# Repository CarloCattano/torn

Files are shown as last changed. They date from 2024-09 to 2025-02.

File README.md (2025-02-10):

This is the 42 Berlin fork of the original torn v3 project. We would like to make this project available to anyone in the school who has interest, but first we want to reliably be able to build the project and document any extra steps here.

# First Build Troubleshooting Issues

- The OLED display still has glitching issues in a part of the display. We have resoldered it but the glitching persists. So it could be this is another electrical/software issue. This may only be resolved/diagnosed when we've built another one

# Documenting the 2nd Build

During the 2nd build we will try to document the trickier parts to pay attention and/or create new sections documentation that diverges from the original. So far we have identified the following issues:

1. Choice of Case

It helps to consider which case you might build even from the get-go, as it can affect which buttons you choose (see below) and for some cases the switches/keycaps need to be of a certain type.

What we tried to far:
- PCB Case: We noted that there are no .svg files provided for laser cutting the parts, we must create our own from the Kicad projects (base and plate). This requires a few design decisions (indent around USB connector etc)
- HiPro Case: Be aware that there are two variations here for MX or Choc switches

2. USB Connector

- These should be soldered and tested with someone with plenty of experience and getting it wrong can ruin the whole rest of the build.
- Right now we are hand soldering with the finest tip we have, and it's still tricky.
- As the pins do not stick out fully, an alternative approach could be to use solder paste, a heat gun and flux.
- We should consider redesigning this for a more hand-soldering friendly connector (if such a thing exists) 
- Without a solution here, it prevents the build from being achievable by all

3. Buttons

The choice of height of the two reset/boot buttons is important. For the first build we used very flat buttons, only later to discover that they are inaccessible when adding the transparent acrylic layer on top. The solution to this would be to use taller buttons (we have them in different sizes in a kit) and to cut holes in the acrylic layer to allow the buttons to poke through.

4. Flashing the Bootloader

We have an Arduino set aside in a box to help with flashing the bootloader
The original guide has the right instructions in terms of pinouts, but it's easy to the wiring up, so for 2nd build we should to document better how to wire the pins to the 6-pin header on the keyboard (photo)

5. Flashing the Firmware

There were two issues here that diverged from the build guide. We installed all the necessary dependencies and tools in the LabAdmin account on the computer on the left next to the window.

- QMKVia which torn v3 uses is no longer supported. We don't have a solution for this, as the support for it its dropped and requires manual intervention and investigation as mentioned in the author isse https://github.com/rtitmuss/torn/issues/29

- The make command to be run from the qmk_firmware folder is ```make torn:default:flash``` as opposed to the guide. Keyboard must be set to flashing mode.

6. Configuration

- A C file is used to configure the keyboard [keymap file](https://github.com/qmk/qmk_firmware/blob/master/keyboards/torn/keymaps/default/keymap.c). This could be improved by adding a wrapper. Any alterations require compiling and flashing to the chip, which could complicate things though

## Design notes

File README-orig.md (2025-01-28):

Torn
===============

The split keyboard kit made with through hole components. The design has been inspired by the [Corne](https://github.com/foostan/crkbd), [Plaid](https://github.com/hsgw/plaid) and [Discipline](https://github.com/coseyfannitutti/discipline) keyboards.

torn

Torn uses an Atmega328P cpu, running QMK with VUSB:
- [QMK firmware](https://github.com/qmk/qmk_firmware/blob/master/keyboards/torn/readme.md).
- [Bootloader](https://github.com/rtitmuss/USBaspLoader).
- Compatible with [VIA](https://caniusevia.com/)

## Building your own Torn keyboard

Later this year you will be able to buy a Torn keyboard kit from [splitkb.com](https://blog.splitkb.com/blog/january-2021).
Alternatively you can also buy [all the parts](./doc/bom.md) needed youself.

Instructions are in the [Build guide](./doc/build.md) and [Troubleshooting guide](./doc/troubleshoot.md).
You can ask questions and get help on the [Torn Discord channel](https://discord.gg/mamAqNccju).

There is also a detailed [build log](https://github.com/rafaeldelboni/buildlogs/blob/main/torn-v3.md)
and [video](https://www.youtube.com/watch?v=7WUTQ30Datw). Thanks [rafaeldelboni](https://github.com/rafaeldelboni)! 

## Thanks

It would not have been possible for me to design Torn without the information and designs published by the mechanical keyboard community. So thanks go to ...

### Guides

* [Corne Keyboard build log](https://thomasbaart.nl/2018/11/26/corne-keyboard-helidox-build-log/) was my first step into this rabbit hole ...
* [Keyboard PCB Guide](https://github.com/ruiqimao/keyboard-pcb-guide) a beginners guide to designing a keyboard PCB in KiCad
* [Guide: Keyboard Construction Explained](https://brianlee.blog/2018/11/23/guide-keyboard-construction-explained/)
* [Cheat sheet: Custom keyboard mounting styles](https://thomasbaart.nl/2019/04/07/cheat-sheet-custom-keyboard-mounting-styles/)

### PCB Design

* [KiCad](https://kicad.org/) for PCB design
* [Split keyboard comparison site](https://jhelvy.shinyapps.io/splitkbcompare/) to iterate on key layout
* [Keyboard layout editor](http://www.keyboard-layout-editor.com/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,%3B&@_y:-0.875&x:2%3B&=X&_x:1%3B&=V&_x:5%3B&=M&_x:1%3B&=.%3B&@_y:-0.875&x:5%3B&=B&_x:3%3B&=N%3B&@_y:-0.875&a:7%3B&=&_a:4%3B&=Z&_x:11&a:7%3B&=&=%3B&@_y:-0.2749999999999999&x:3%3B&=&_x:7%3B&=%3B&@_r:13&rx:3.5&ry:8.5&y:-5.4&x:-0.5%3B&=%3B&@_r:26&y:-1&x:-0.5%3B&=%3B&@_r:39&y:-1&x:-0.5%3B&=%3B&@_r:-39&rx:11.5&y:-5.4&x:-0.5%3B&=%3B&@_r:-26&y:-1&x:-0.5%3B&=%3B&@_r:-13&y:-1&x:-0.5%3B&=) for your layout
* [Plate & Case Builder](http://builder.swillkb.com/) Generate CAD files from KLE files
* [keyswitches.pretty](https://github.com/daprice/keyswitches.pretty) KiCad library of mechanical keyboard switch footprints 

### QMK Firmware

* [QMK](https://docs.qmk.fm/#/) Quantum Mechanical Keyboard firmware
* [REMAP](https://remap-keys.app/) to easily configure your keyboard online
* [VIA](https://caniusevia.com/) to configure your keyboard

### 3d Design

The following are great resources to get started with keyboard case design:

* [Fusion 360](https://www.autodesk.com/products/fusion-360/personal)
* [65% Keyboard Case Design](https://youtu.be/4P0zfLLblOw)
* [Hinged Box for 3D Printing](https://youtu.be/iSBsBTMsGTk)
* [Snap Fit Cases](https://www.youtube.com/watch?v=E0NVC8xhf3I)
* [Knurling for 3D Printing](https://www.youtube.com/watch?v=jKPbye0XtMk)

### Other Keyboards

I took inspiration from other keyboards I'd used or liked:

* [Kinesis Advantage](https://kinesis-ergo.com/shop/advantage2/) my daily driver and endgame for almost 20 years! Opps! 
* [Corne](https://github.com/foostan/crkbd)
* [Discipline](https://github.com/coseyfannitutti/discipline) (used with permission from [coseyfannitutti](https://github.com/coseyfannitutti/))
* [Plaid](https://github.com/hsgw/plaid)
* [Lily](https://docs-gitbook.keeb.io/docs/iris-rev3-build-guide)
* [Dactyl](https://raw.githubusercontent.com/adereth/dactyl-keyboard/master/guide/circuit-diagram.png)

## License



The Torn Keyboard is licensed under [Creative Commons Attribution-NonCommercial 4.0 International License](https://creativecommons.org/licenses/by-nc/4.0).

This PCB design may be freely reproduced, modified, and manufactured for personal use only. If you would like to use this design commercially please contact me at richard.titmuss@gmail.com to request permission.
 
## Gallery

Build Photo

Torn Keyboard

Wedge Case

Choc Switches

HiPro Case

3d Case

Torn Keyboard

Torn Keyboard

Torn Keyboard

Torn Keyboard

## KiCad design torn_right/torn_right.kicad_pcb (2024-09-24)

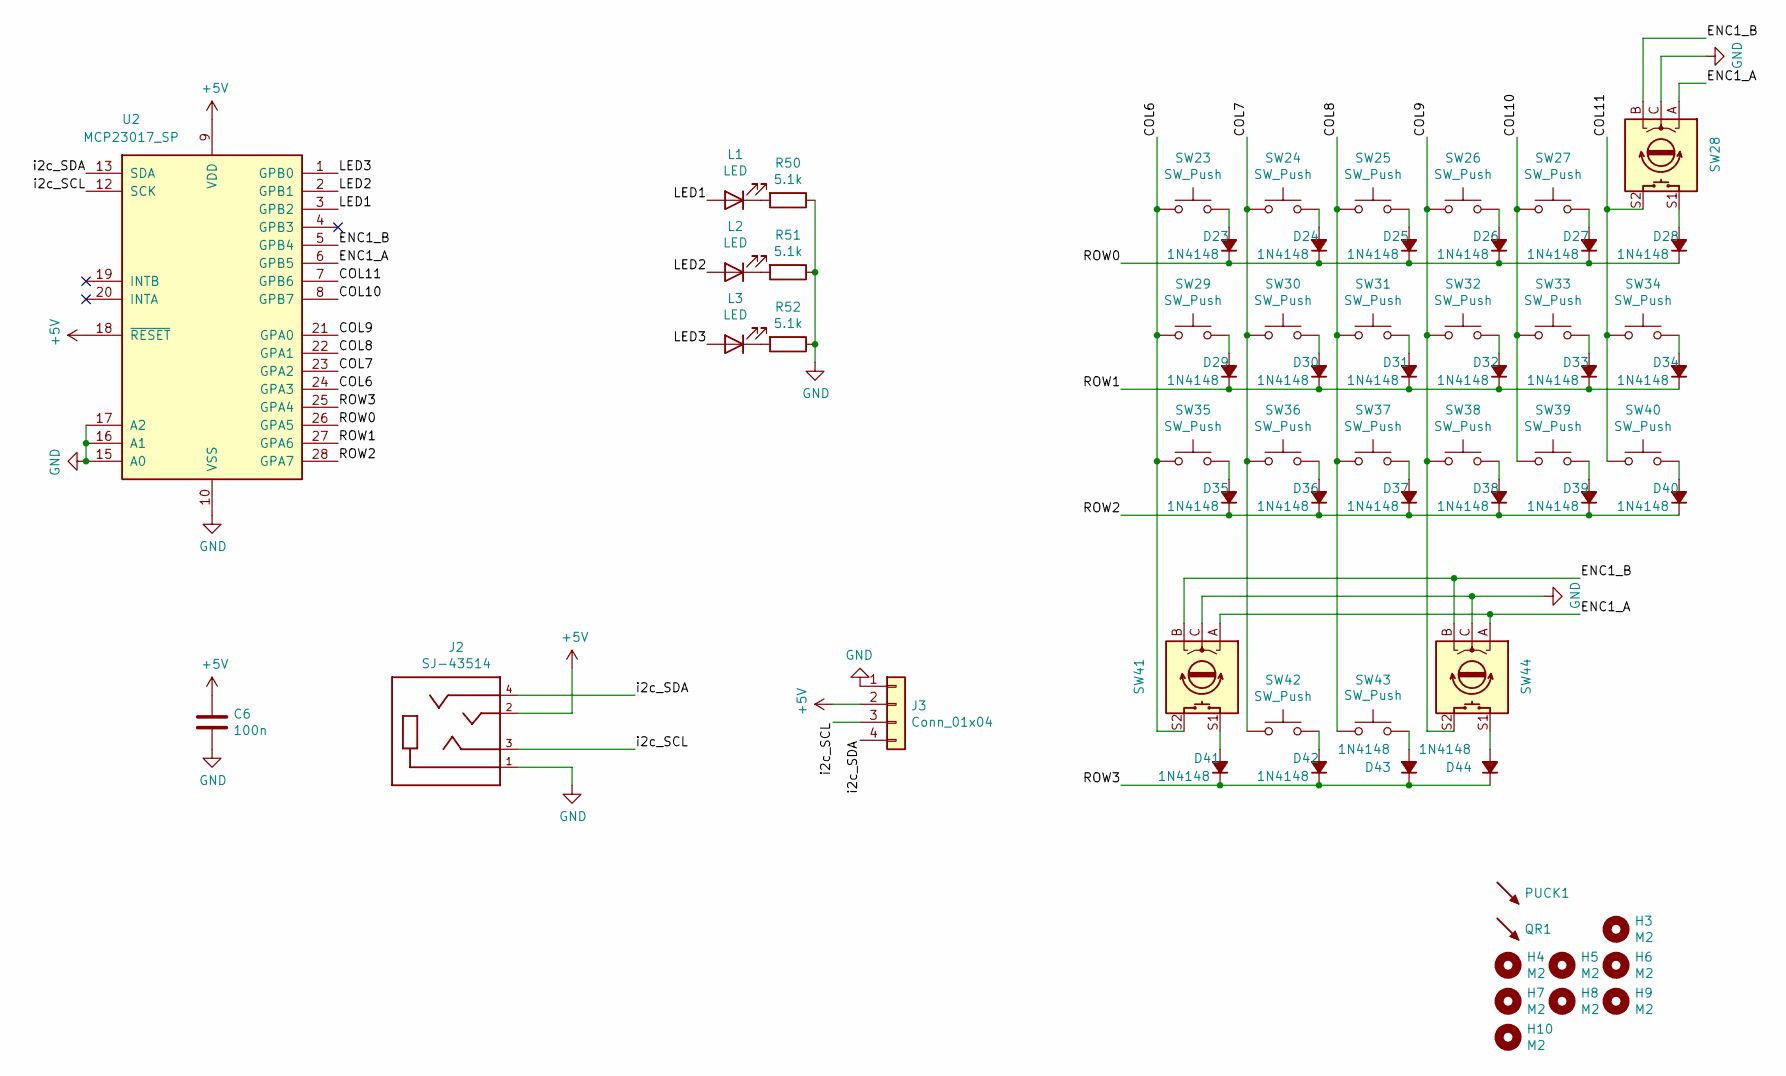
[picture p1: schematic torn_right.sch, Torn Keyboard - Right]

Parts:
C6: 100n; C_Disc_D4.3mm_W1.9mm_P5.00mm
D23, D24, D25, D26, D27, D28, D29, D30, D31, D32, D33, D34, D35, D36, D37, D38, D39, D40, D41, D42, D43, D44: 1N4148; D_DO-35_SOD27_P5.08mm_Horizontal
H3, H4, H5, H6, H7, H8, H9, H10: M2; MountingHole_2.2mm_M2_Pad
J2: SJ-43514; PJ-320A
J3: Conn_01x04; OLED_1side
L1, L2, L3: LED; LED_D3.0mm
PUCK1: PUCK; Tenting_Puck
QR1: SYM_Arrow45_Small; torn_qr_code
R50, R51, R52: 5.1k; R_Axial_DIN0204_L3.6mm_D1.6mm_P5.08mm_Horizontal
SW23, SW24, SW25, SW26, SW27, SW29, SW30, SW31, SW32, SW33, SW34, SW35, SW36, SW37, SW38, SW39, SW40, SW42, SW43: SW_Push; Kailh_socket_MX_PG1350_optional
SW28, SW41, SW44: Rotary_Encoder_Switch; Kailh_socket_MX_PG1350_EC11_optional
U2: MCP23017_SP; DIP-28_W7.62mm_Socket

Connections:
+5V: C6.1, J2.2, J3.2, U2.9 (VDD), U2.18 (~RESET~)
/COL6: SW23.2, SW29.2, SW35.2, SW41.S2, U2.24 (GPA3)
/COL7: SW24.2, SW30.2, SW36.2, SW42.2, U2.23 (GPA2)
/COL8: SW25.2, SW31.2, SW37.2, SW43.2, U2.22 (GPA1)
/COL9: SW26.2, SW32.2, SW38.2, SW44.S2, U2.21 (GPA0)
/COL10: SW27.2, SW33.2, SW39.2, U2.8 (GPB7)
/COL11: SW28.S2, SW34.2, SW40.2, U2.7 (GPB6)
/ENC1_A: SW28.A, SW41.A, SW44.A, U2.6 (GPB5)
/ENC1_B: SW28.B, SW41.B, SW44.B, U2.5 (GPB4)
/LED1: L1.2 (A), U2.3 (GPB2)
/LED2: L2.2 (A), U2.2 (GPB1)
/LED3: L3.2 (A), U2.1 (GPB0)
/ROW0: D23.1 (K), D24.1 (K), D25.1 (K), D26.1 (K), D27.1 (K), D28.1 (K), U2.26 (GPA5)
/ROW1: D29.1 (K), D30.1 (K), D31.1 (K), D32.1 (K), D33.1 (K), D34.1 (K), U2.27 (GPA6)
/ROW2: D35.1 (K), D36.1 (K), D37.1 (K), D38.1 (K), D39.1 (K), D40.1 (K), U2.28 (GPA7)
/ROW3: D41.1 (K), D42.1 (K), D43.1 (K), D44.1 (K), U2.25 (GPA4)
/i2c_SCL: J2.3, J3.3, U2.12 (SCK)
/i2c_SDA: J2.4, J3.4, U2.13 (SDA)
GND: C6.2, J2.1, J3.1, R50.1, R51.1, R52.1, SW28.C, SW41.C, SW44.C, U2.10 (VSS), U2.15 (A0), U2.16 (A1), U2.17 (A2)
unnamed: D23.2 (A), SW23.1
unnamed: D24.2 (A), SW24.1
unnamed: D25.2 (A), SW25.1
unnamed: D26.2 (A), SW26.1
unnamed: D27.2 (A), SW27.1
unnamed: D28.2 (A), SW28.S1
unnamed: D29.2 (A), SW29.1
unnamed: D30.2 (A), SW30.1
unnamed: D31.2 (A), SW31.1
unnamed: D32.2 (A), SW32.1
unnamed: D33.2 (A), SW33.1
unnamed: D34.2 (A), SW34.1
unnamed: D35.2 (A), SW35.1
unnamed: D36.2 (A), SW36.1
unnamed: D37.2 (A), SW37.1
unnamed: D38.2 (A), SW38.1
unnamed: D39.2 (A), SW39.1
unnamed: D40.2 (A), SW40.1
unnamed: D41.2 (A), SW41.S1
unnamed: D42.2 (A), SW42.1
unnamed: D43.2 (A), SW43.1
unnamed: D44.2 (A), SW44.S1
unnamed: L1.1 (K), R50.2
unnamed: L2.1 (K), R51.2
unnamed: L3.1 (K), R52.2

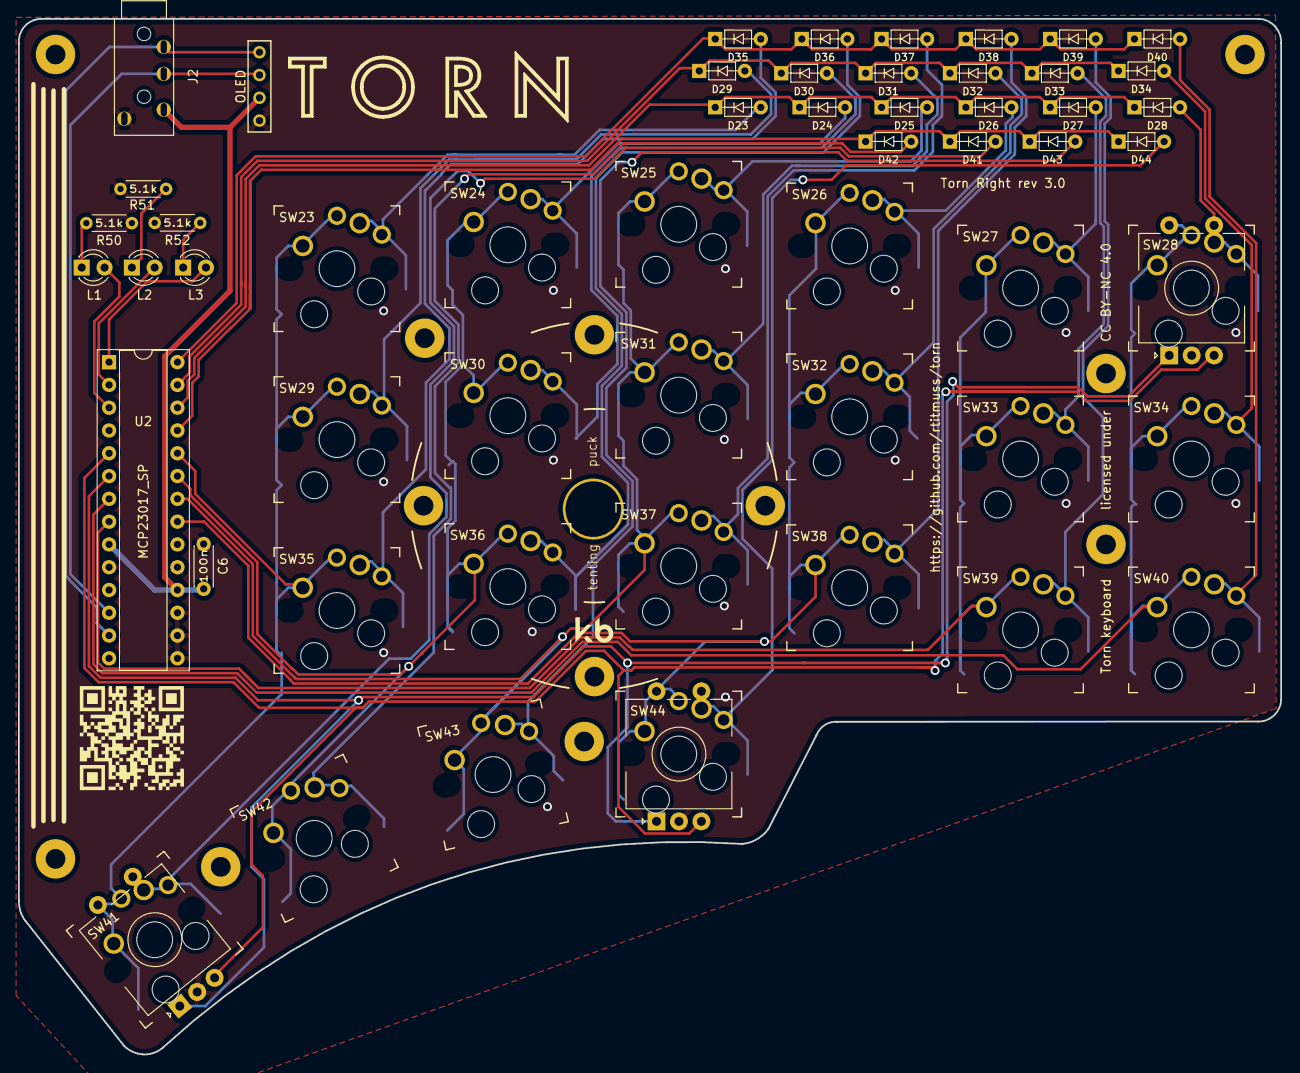
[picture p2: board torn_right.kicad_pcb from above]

Board: 2 copper layers, 140.7 x 115.4 mm, 64 parts (0 on the bottom side), 44 nets.

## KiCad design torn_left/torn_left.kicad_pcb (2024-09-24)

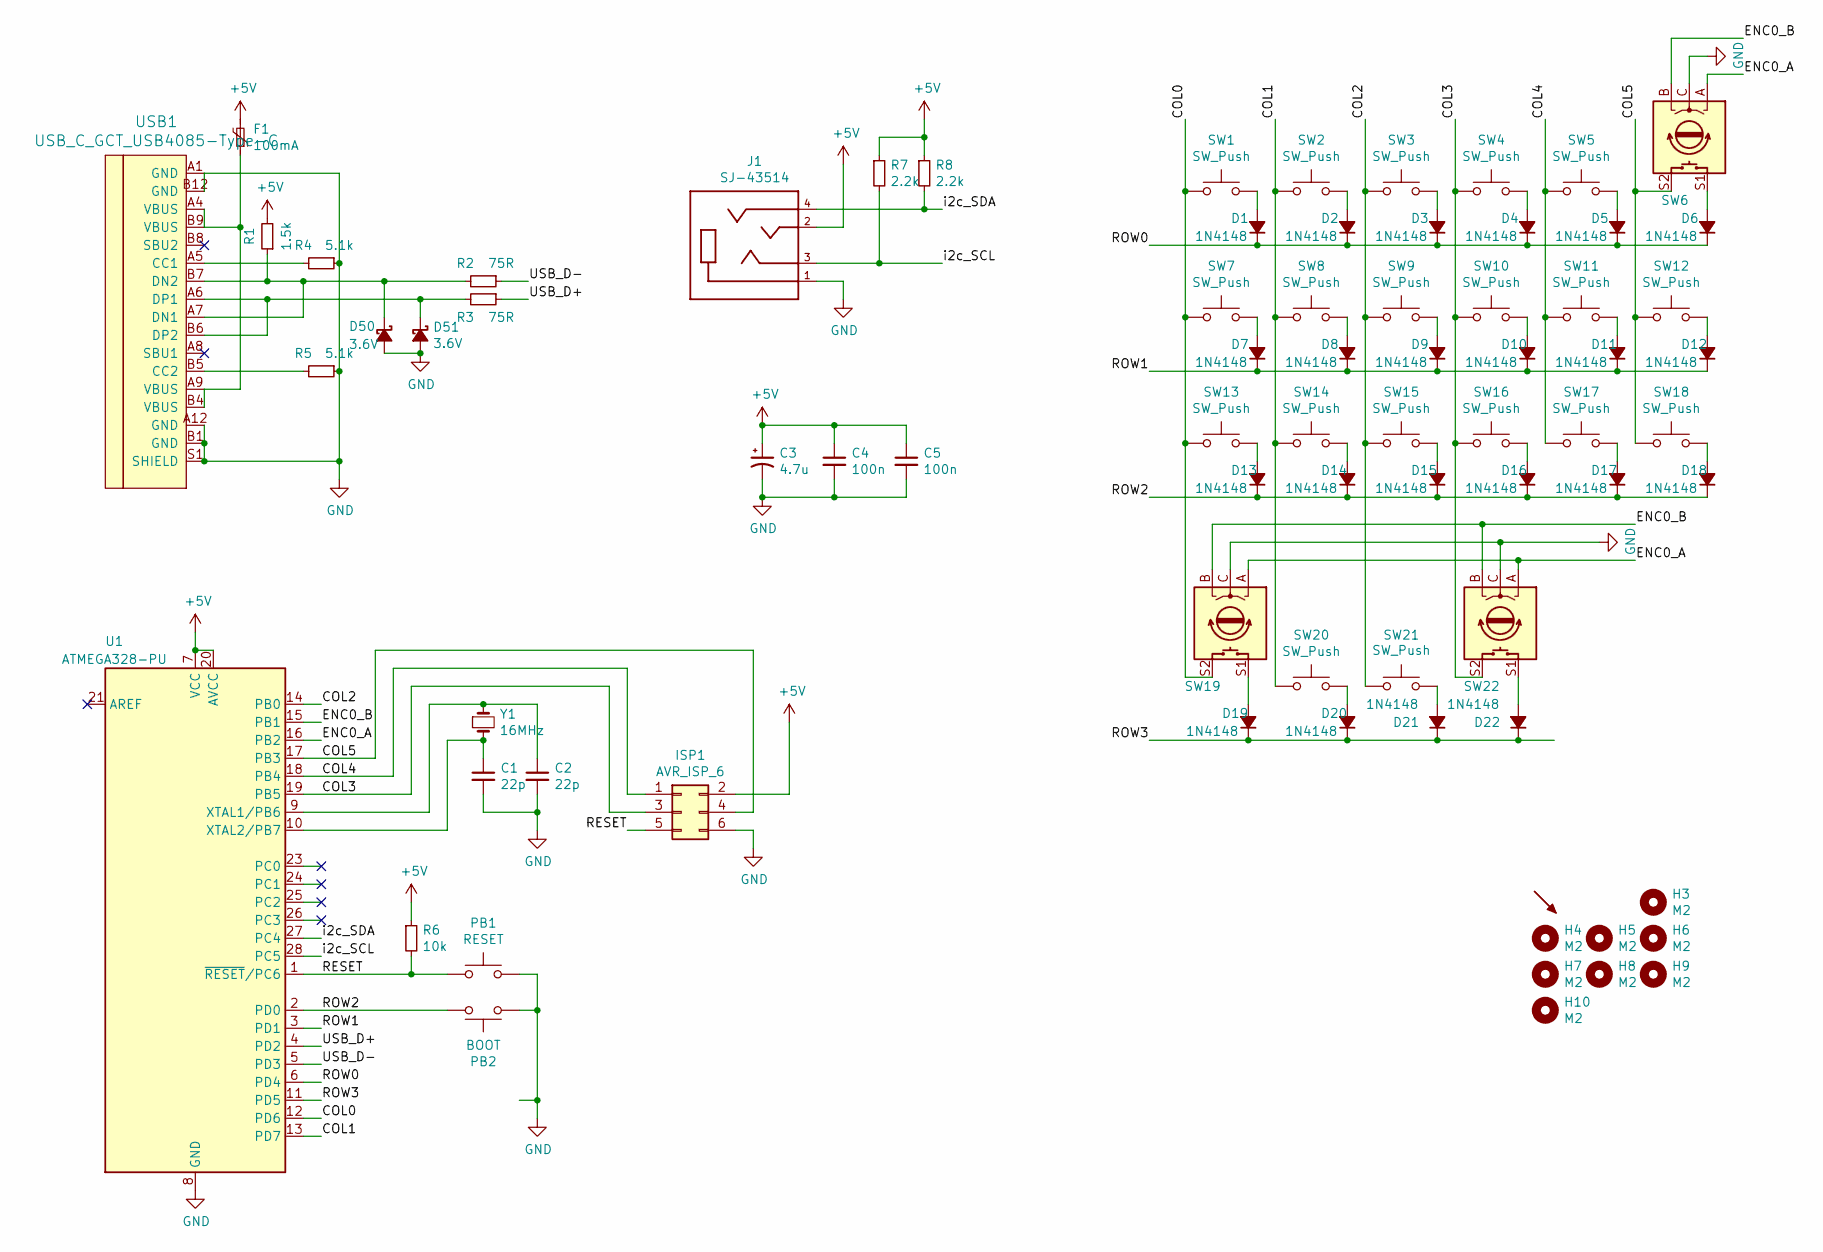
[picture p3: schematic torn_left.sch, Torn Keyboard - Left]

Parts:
C1, C2: 22p; C_Disc_D3.0mm_W1.6mm_P2.50mm
C3: 4.7u; CP_Radial_D4.0mm_P1.50mm
C4, C5: 100n; C_Disc_D4.3mm_W1.9mm_P5.00mm
D1, D2, D3, D4, D5, D6, D7, D8, D9, D10, D11, D12, D13, D14, D15, D16, D17, D18, D19, D20, D21, D22: 1N4148; D_DO-35_SOD27_P5.08mm_Horizontal
D50, D51: 3.6V; D_DO-35_SOD27_P5.08mm_Horizontal
F1: 100mA; polyfuse_5.1mm
H3, H4, H5, H6, H7, H8, H9, H10: M2; MountingHole_2.2mm_M2_Pad
ISP1: AVR_ISP_6; AVR_ICSP_3x2
J1: SJ-43514; PJ-320A
PB1: RESET; SW_PUSH_6mm
PB2: BOOT; SW_PUSH_6mm
PUCK1: SYM_Arrow45_Small; Tenting_Puck
R1: 1.5k; R_Axial_DIN0204_L3.6mm_D1.6mm_P5.08mm_Horizontal
R2, R3: 75R; R_Axial_DIN0204_L3.6mm_D1.6mm_P5.08mm_Horizontal
R4, R5: 5.1k; R_Axial_DIN0204_L3.6mm_D1.6mm_P5.08mm_Horizontal
R6: 10k; R_Axial_DIN0204_L3.6mm_D1.6mm_P5.08mm_Horizontal
R7, R8: 2.2k; R_Axial_DIN0204_L3.6mm_D1.6mm_P5.08mm_Horizontal
SW1, SW2, SW3, SW4, SW5, SW7, SW8, SW9, SW10, SW11, SW12, SW13, SW14, SW15, SW16, SW17, SW18, SW20, SW21: SW_Push; Kailh_socket_MX_PG1350_optional
SW6, SW19, SW22: Rotary_Encoder_Switch; Kailh_socket_MX_PG1350_EC11_optional
U1: ATMEGA328-PU; DIP-28_W7.62mm_Socket
USB1: USB_C_GCT_USB4085-Type-C; USB_C_GCT_USB4085
Y1: 16MHz; Crystal_HC49-4H_Vertical

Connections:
+5V: C3.1, C4.1, C5.1, F1.2, ISP1.2, J1.2, R1.2, R6.1, R7.1, R8.1, U1.7 (VCC), U1.20 (AVCC)
/COL0: SW1.2, SW7.2, SW13.2, SW19.S2, U1.12 (PD6)
/COL1: SW2.2, SW8.2, SW14.2, SW20.2, U1.13 (PD7)
/COL2: SW3.2, SW9.2, SW15.2, SW21.2, U1.14 (PB0)
/COL3: ISP1.3, SW4.2, SW10.2, SW16.2, SW22.S2, U1.19 (PB5)
/COL4: ISP1.1, SW5.2, SW11.2, SW17.2, U1.18 (PB4)
/COL5: ISP1.4, SW6.S2, SW12.2, SW18.2, U1.17 (PB3)
/ENC0_A: SW6.A, SW19.A, SW22.A, U1.16 (PB2)
/ENC0_B: SW6.B, SW19.B, SW22.B, U1.15 (PB1)
/RESET: ISP1.5, PB1.1, R6.2, U1.1 (~RESET~/PC6)
/ROW0: D1.1 (K), D2.1 (K), D3.1 (K), D4.1 (K), D5.1 (K), D6.1 (K), U1.6 (PD4)
/ROW1: D7.1 (K), D8.1 (K), D9.1 (K), D10.1 (K), D11.1 (K), D12.1 (K), U1.3 (PD1)
/ROW2: D13.1 (K), D14.1 (K), D15.1 (K), D16.1 (K), D17.1 (K), D18.1 (K), PB2.2, U1.2 (PD0)
/ROW3: D19.1 (K), D20.1 (K), D21.1 (K), D22.1 (K), U1.11 (PD5)
/USB_D+: R3.1, U1.4 (PD2)
/USB_D-: R2.1, U1.5 (PD3)
/i2c_SCL: J1.3, R7.2, U1.28 (PC5)
/i2c_SDA: J1.4, R8.2, U1.27 (PC4)
GND: C1.2, C2.2, C3.2, C4.2, C5.2, D50.2 (A), D51.2 (A), ISP1.6, J1.1, PB1.2, PB2.1, R4.1, R5.1, SW6.C, SW19.C, SW22.C, U1.8 (GND), U1.22 (GND), USB1.A1 (GND), USB1.A12 (GND), USB1.B1 (GND), USB1.B12 (GND), USB1.S1 (SHIELD)
unnamed: C1.1, U1.10 (XTAL2/PB7), Y1.2
unnamed: C2.1, U1.9 (XTAL1/PB6), Y1.1
unnamed: D1.2 (A), SW1.1
unnamed: D2.2 (A), SW2.1
unnamed: D3.2 (A), SW3.1
unnamed: D4.2 (A), SW4.1
unnamed: D5.2 (A), SW5.1
unnamed: D6.2 (A), SW6.S1
unnamed: D7.2 (A), SW7.1
unnamed: D8.2 (A), SW8.1
unnamed: D9.2 (A), SW9.1
unnamed: D10.2 (A), SW10.1
unnamed: D11.2 (A), SW11.1
unnamed: D12.2 (A), SW12.1
unnamed: D13.2 (A), SW13.1
unnamed: D14.2 (A), SW14.1
unnamed: D15.2 (A), SW15.1
unnamed: D16.2 (A), SW16.1
unnamed: D17.2 (A), SW17.1
unnamed: D18.2 (A), SW18.1
unnamed: D19.2 (A), SW19.S1
unnamed: D20.2 (A), SW20.1
unnamed: D21.2 (A), SW21.1
unnamed: D22.2 (A), SW22.S1
unnamed: D50.1 (K), R1.1, R2.2, USB1.A7 (DN1), USB1.B7 (DN2)
unnamed: D51.1 (K), R3.2, USB1.A6 (DP1), USB1.B6 (DP2)
unnamed: F1.1, USB1.A4 (VBUS), USB1.A9 (VBUS), USB1.B4 (VBUS), USB1.B9 (VBUS)
unnamed: R4.2, USB1.A5 (CC1)
unnamed: R5.2, USB1.B5 (CC2)

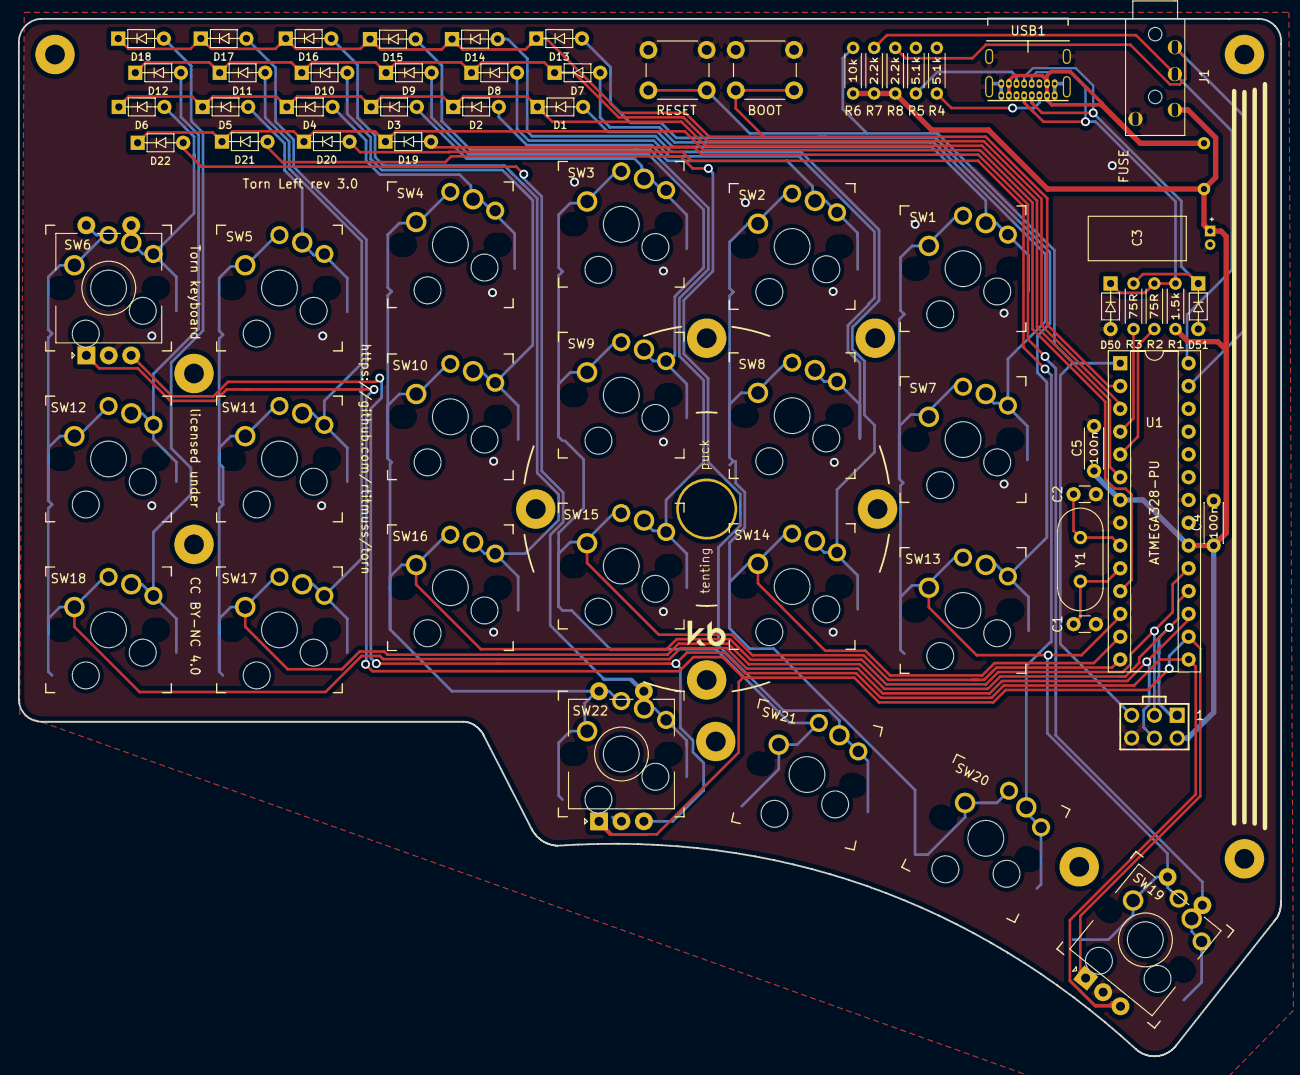
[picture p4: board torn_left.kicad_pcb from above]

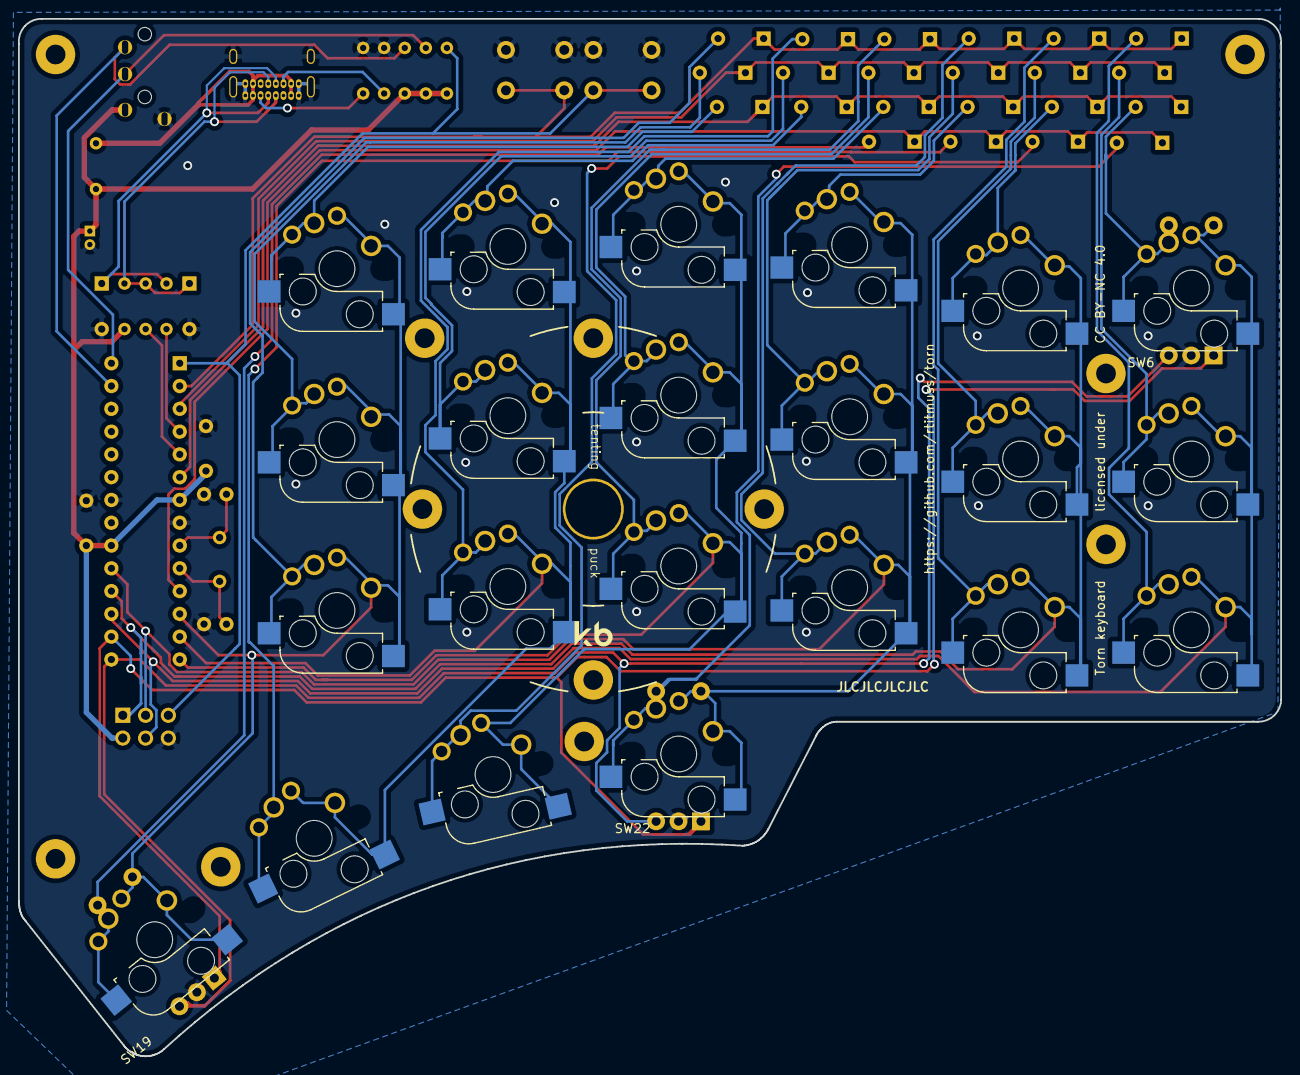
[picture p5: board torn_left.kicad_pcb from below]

Board: 2 copper layers, 140.7 x 115.6 mm, 76 parts (8 on the bottom side), 48 nets.

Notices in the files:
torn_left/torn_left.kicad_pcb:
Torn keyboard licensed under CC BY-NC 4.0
